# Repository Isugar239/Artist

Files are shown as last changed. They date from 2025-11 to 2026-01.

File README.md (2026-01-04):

# Artist
### here are all files of project "ETZ_Zakharov"
## Schemas
### all schemas were made in Splan8.0
## Programm
### .h files were made in VSCode, without chatGPT
### main file contains all classes from .h files avoid Stepper(you dont need to use it, cause it contains in cart class)
## 3D
### mostly model was made in Autodesk Inventor 24. toothed_rack was downloaded in .step format from mipt site. main file is "робот.ipt"

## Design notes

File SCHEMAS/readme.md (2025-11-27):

# Все схемы выполнены в соответствии с гостом, актуальным на момент создания данного файла

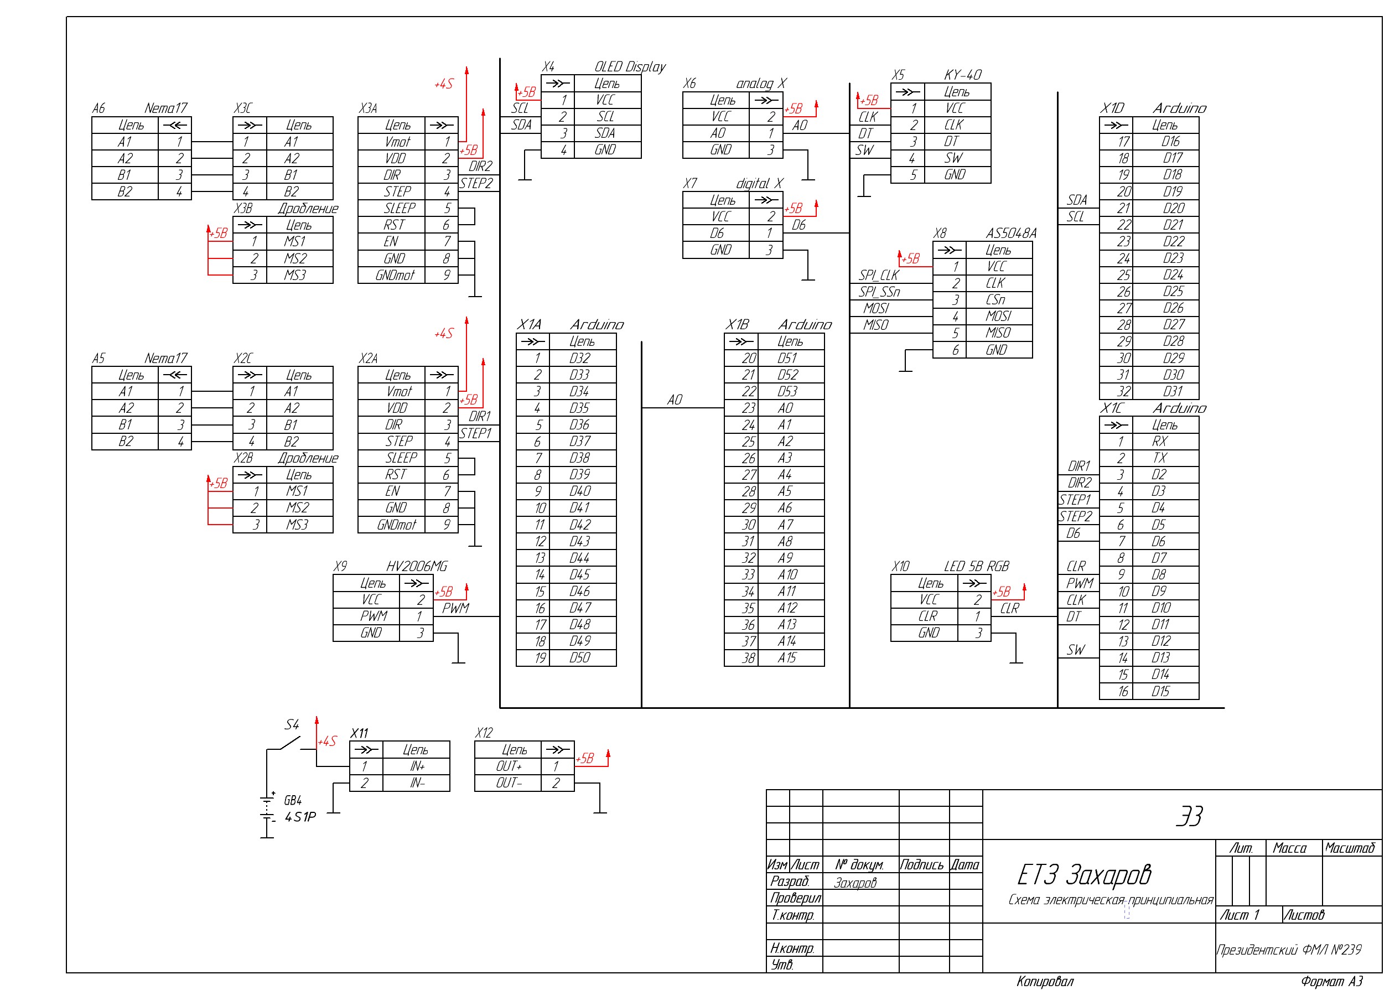
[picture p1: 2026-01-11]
SCHEMAS/Э3_ЕТЗ.jpg

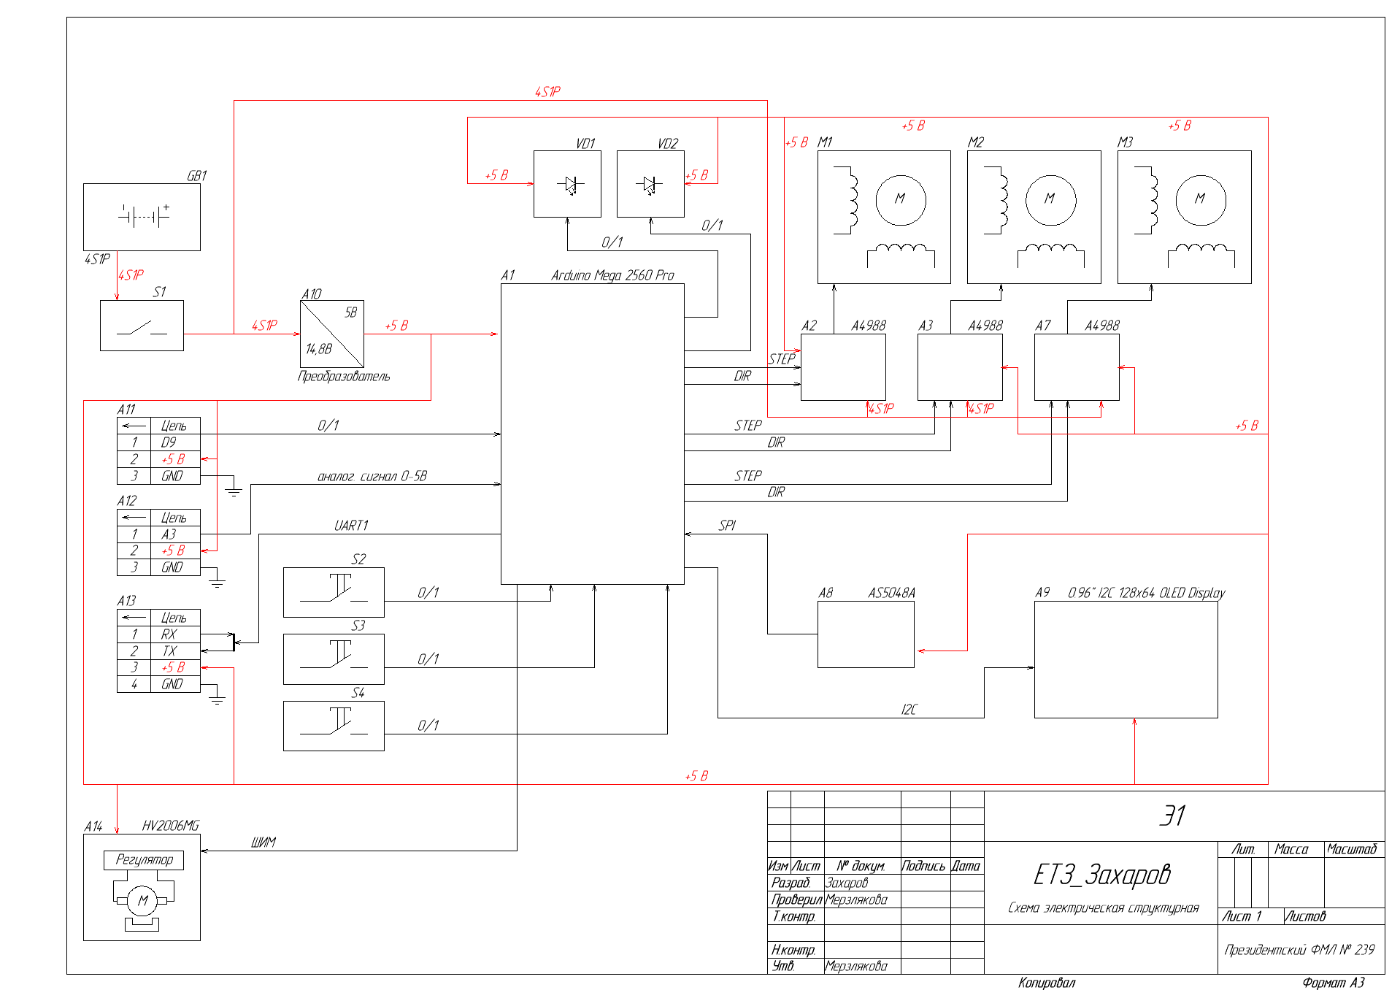
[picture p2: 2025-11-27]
SCHEMAS/Э1_ЕТЗ.png

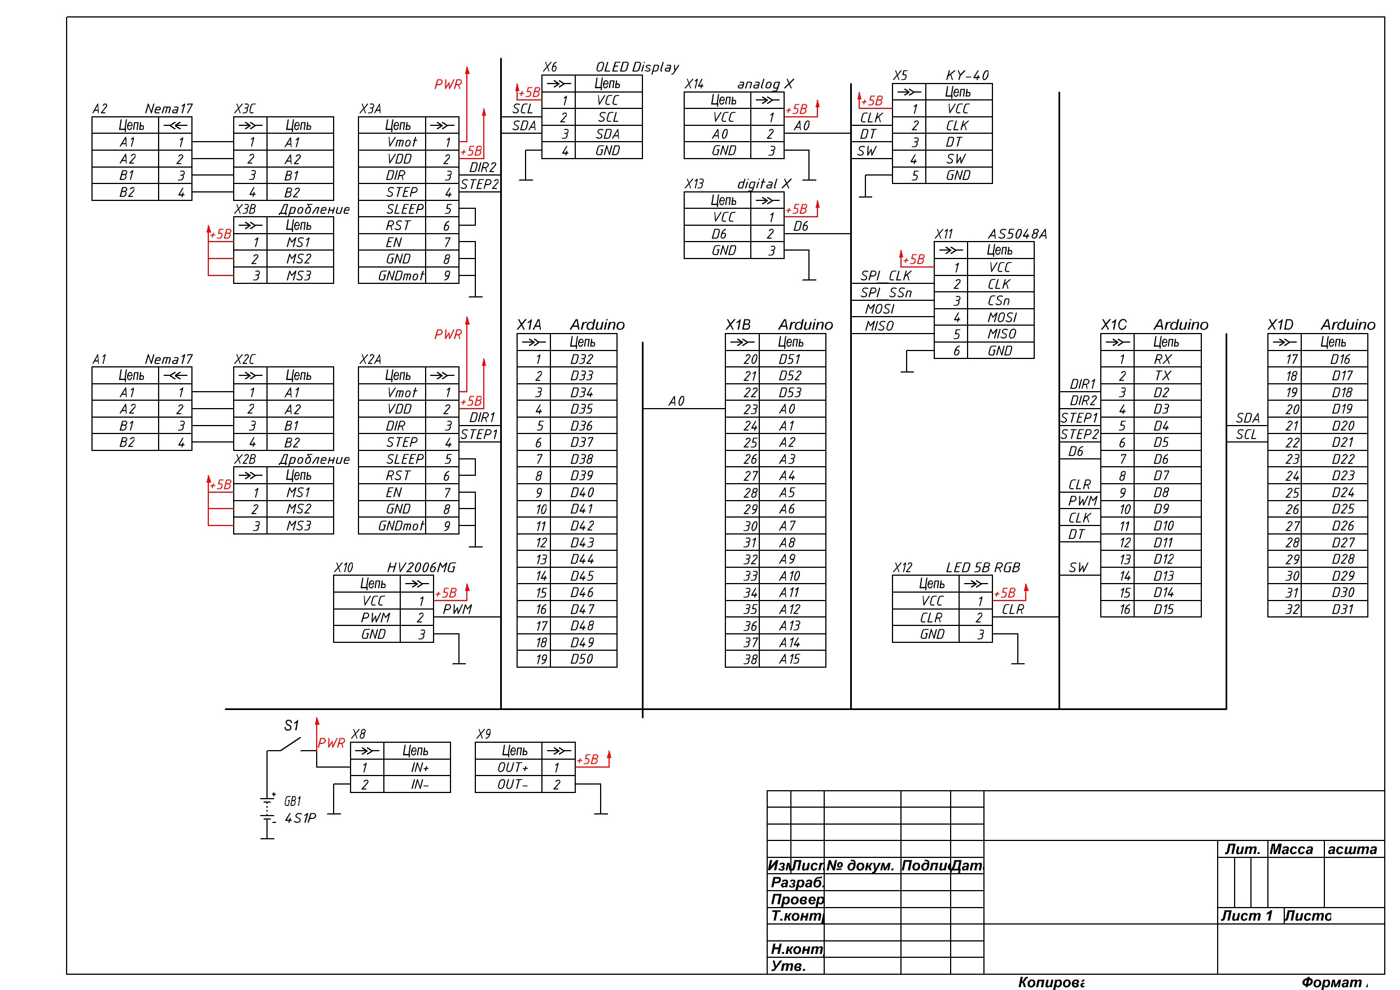
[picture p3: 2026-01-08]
SCHEMAS/э3.jpg

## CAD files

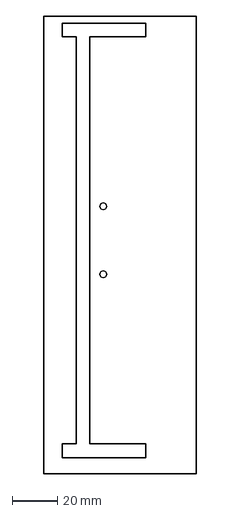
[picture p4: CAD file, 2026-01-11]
3D/dxf/батарейно держалка.dxf
67.3 x 202.1 mm

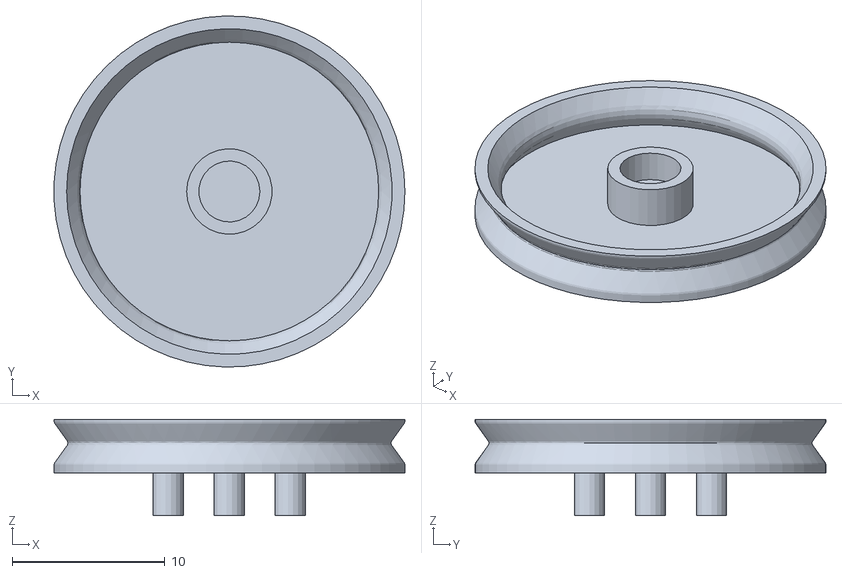
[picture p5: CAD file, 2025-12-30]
3D/для резинки.stl
23.0 x 23.0 x 6.30

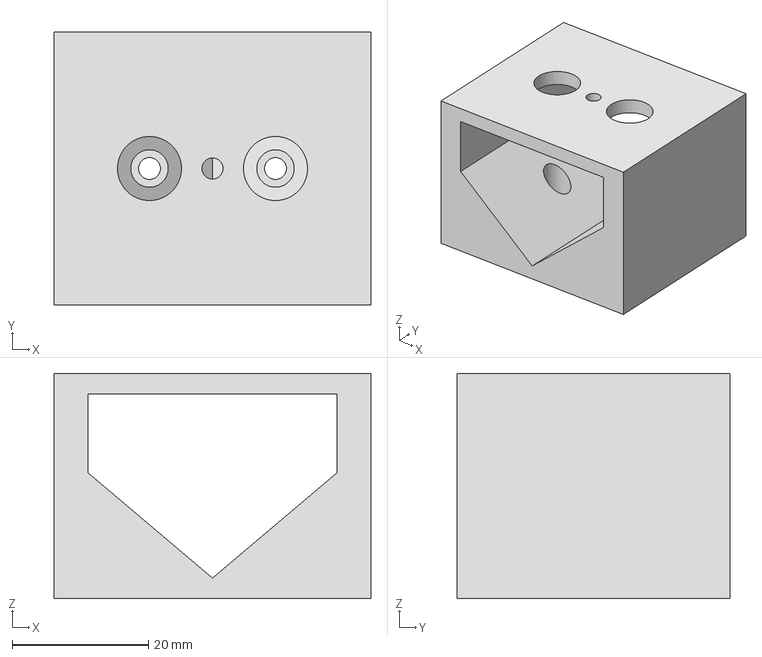
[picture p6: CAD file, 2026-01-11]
3D/стл/верх крепления маркера.stp
46.5 x 40.0 x 33.0 mm

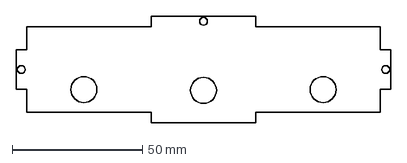
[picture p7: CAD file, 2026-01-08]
3D/dxf/X2_down_balls_mount2.dxf
144.0 x 41.0 mm

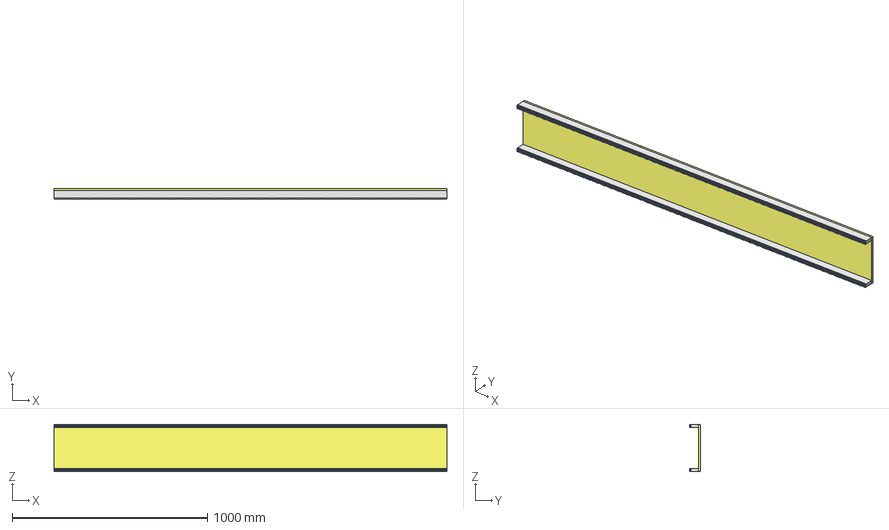
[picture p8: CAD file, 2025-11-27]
3D/полигон етз.stp
2010.6 x 58.0 x 242.7 mm
пол
m2_20_CPY x 10
m2_20_MIR x 10
m2_20_CPY_MIR x 10
брусок
низочек

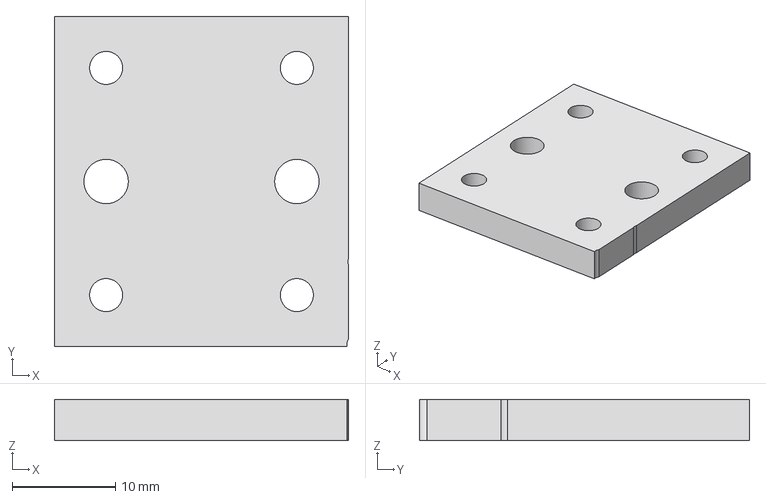
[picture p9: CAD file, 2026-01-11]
3D/стл/полное крепление каретки.stp
28.5 x 32.0 x 4.00 mm

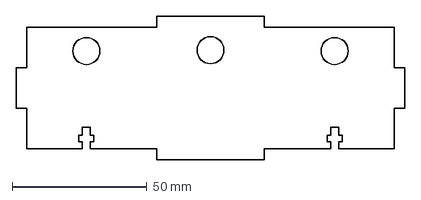
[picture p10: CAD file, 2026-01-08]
3D/dxf/X4_top_mount_balls.dxf
144.0 x 53.0 mm

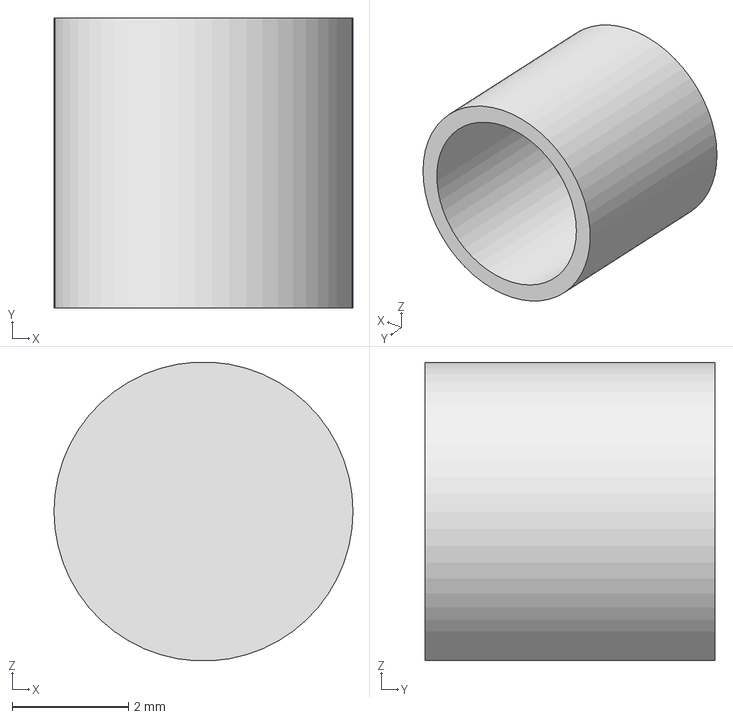
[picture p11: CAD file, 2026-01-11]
3D/стл/на винт для маркера.stp
5.15 x 5.00 x 5.14 mm

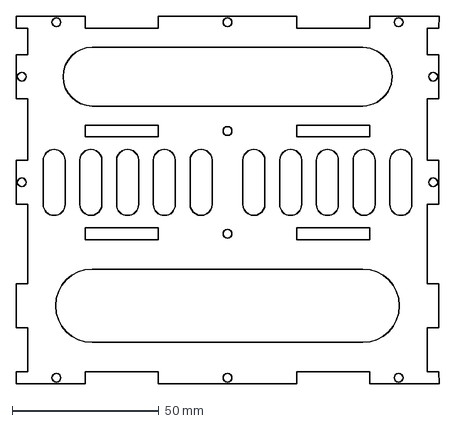
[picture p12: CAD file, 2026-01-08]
3D/dxf/X2_last.dxf
144.0 x 125.0 mm

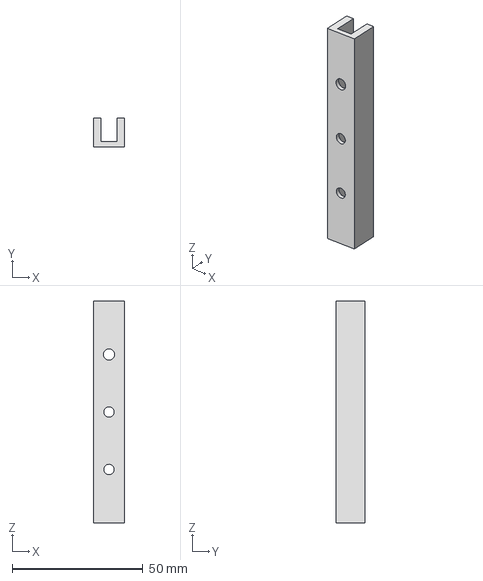
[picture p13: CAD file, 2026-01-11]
3D/стл/красивые провода.stp
12.0 x 11.0 x 85.0 mm

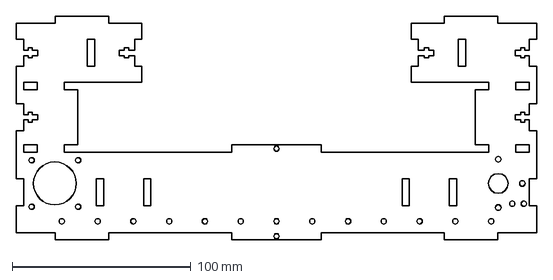
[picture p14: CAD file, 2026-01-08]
3D/dxf/mount_rail.dxf
290.9 x 125.0 mm

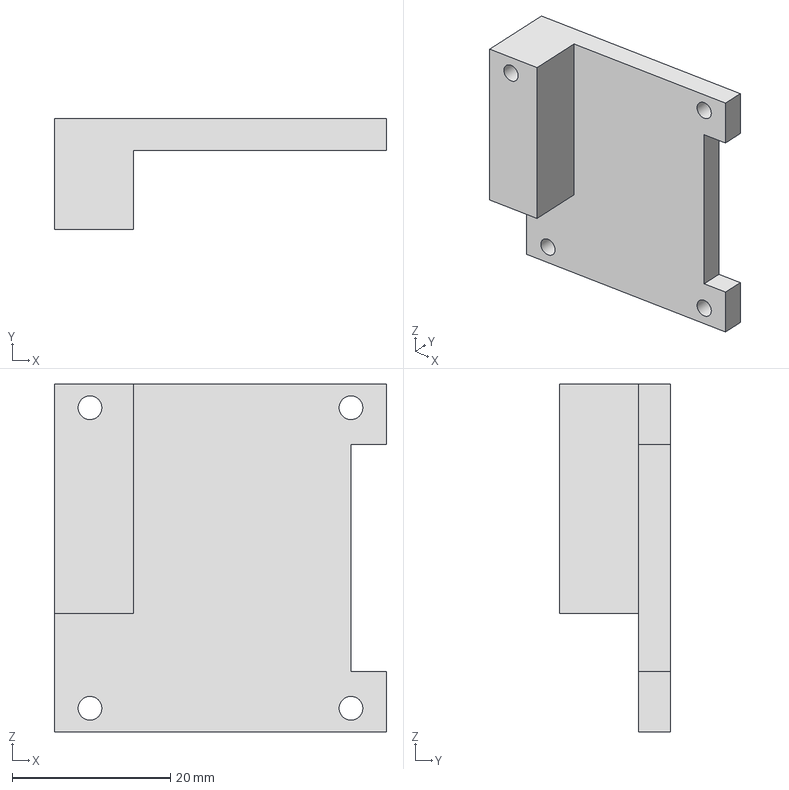
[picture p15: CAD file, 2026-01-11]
3D/стл/экранчик.stp
42.0 x 14.0 x 44.0 mm

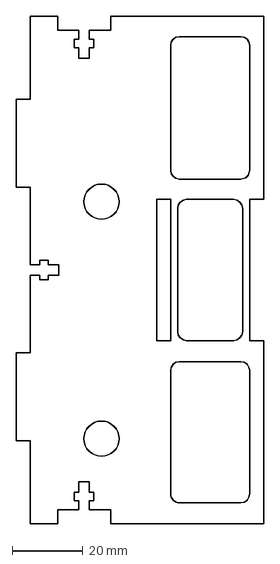
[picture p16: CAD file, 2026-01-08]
3D/dxf/X2_down_down.dxf
70.2 x 144.0 mm

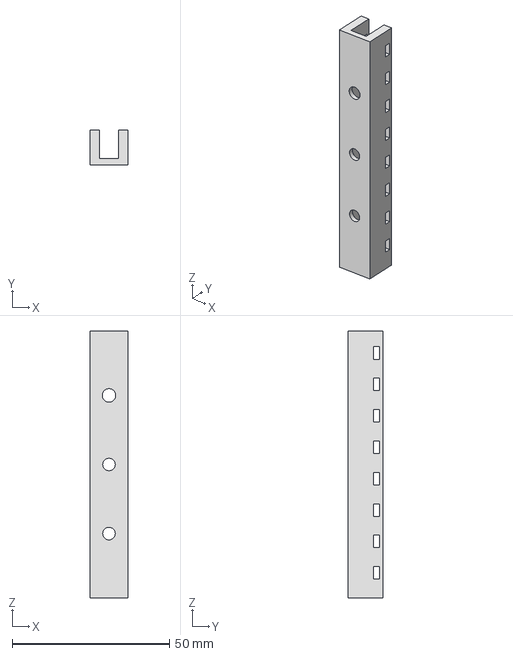
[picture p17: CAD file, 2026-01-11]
3D/стл/новые нормальные провода.stp
12.0 x 11.0 x 85.0 mm

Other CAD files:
3D/полигон_рейки.stl
3D/dxf/задняя крыгка.dxf
3D/стл/крепеж_маркера.stp
3D/dxf/baze_under.dxf
3D/NEMA17 42-40.ipt
3D/OldVersions/NEMA17 42-40.0002.ipt
3D/OldVersions/abs_encider.0002.iam
3D/OldVersions/ЕТЗ.0001.iam
3D/OldVersions/Муфта.0007.ipt
3D/OldVersions/Муфта_MIR.0003.ipt
3D/OldVersions/Нижняя крышка.0019.ipt
3D/OldVersions/ОСНОВА.0005.ipt
3D/OldVersions/Робот.0029.iam
3D/OldVersions/Шест.0007.ipt
3D/OldVersions/Шест_MIR.0002.ipt
3D/OldVersions/боковая стенка.0019.ipt
3D/OldVersions/для резинки.0004.ipt
3D/OldVersions/дно_пробитое.0001.ipt
3D/OldVersions/задняя стенка.0019.ipt
3D/OldVersions/каретка.0008.iam
3D/OldVersions/крепление подшипника_1.0003.ipt
3D/OldVersions/крепление подшипника_1_CPY.0002.ipt
3D/OldVersions/крутящаяся передача.0005.ipt
3D/OldVersions/передняя стенка.0015.ipt
3D/OldVersions/робот-энкодер.0006.ipt
3D/OldVersions/фуллл.0001.iam
3D/abs_encider.iam
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

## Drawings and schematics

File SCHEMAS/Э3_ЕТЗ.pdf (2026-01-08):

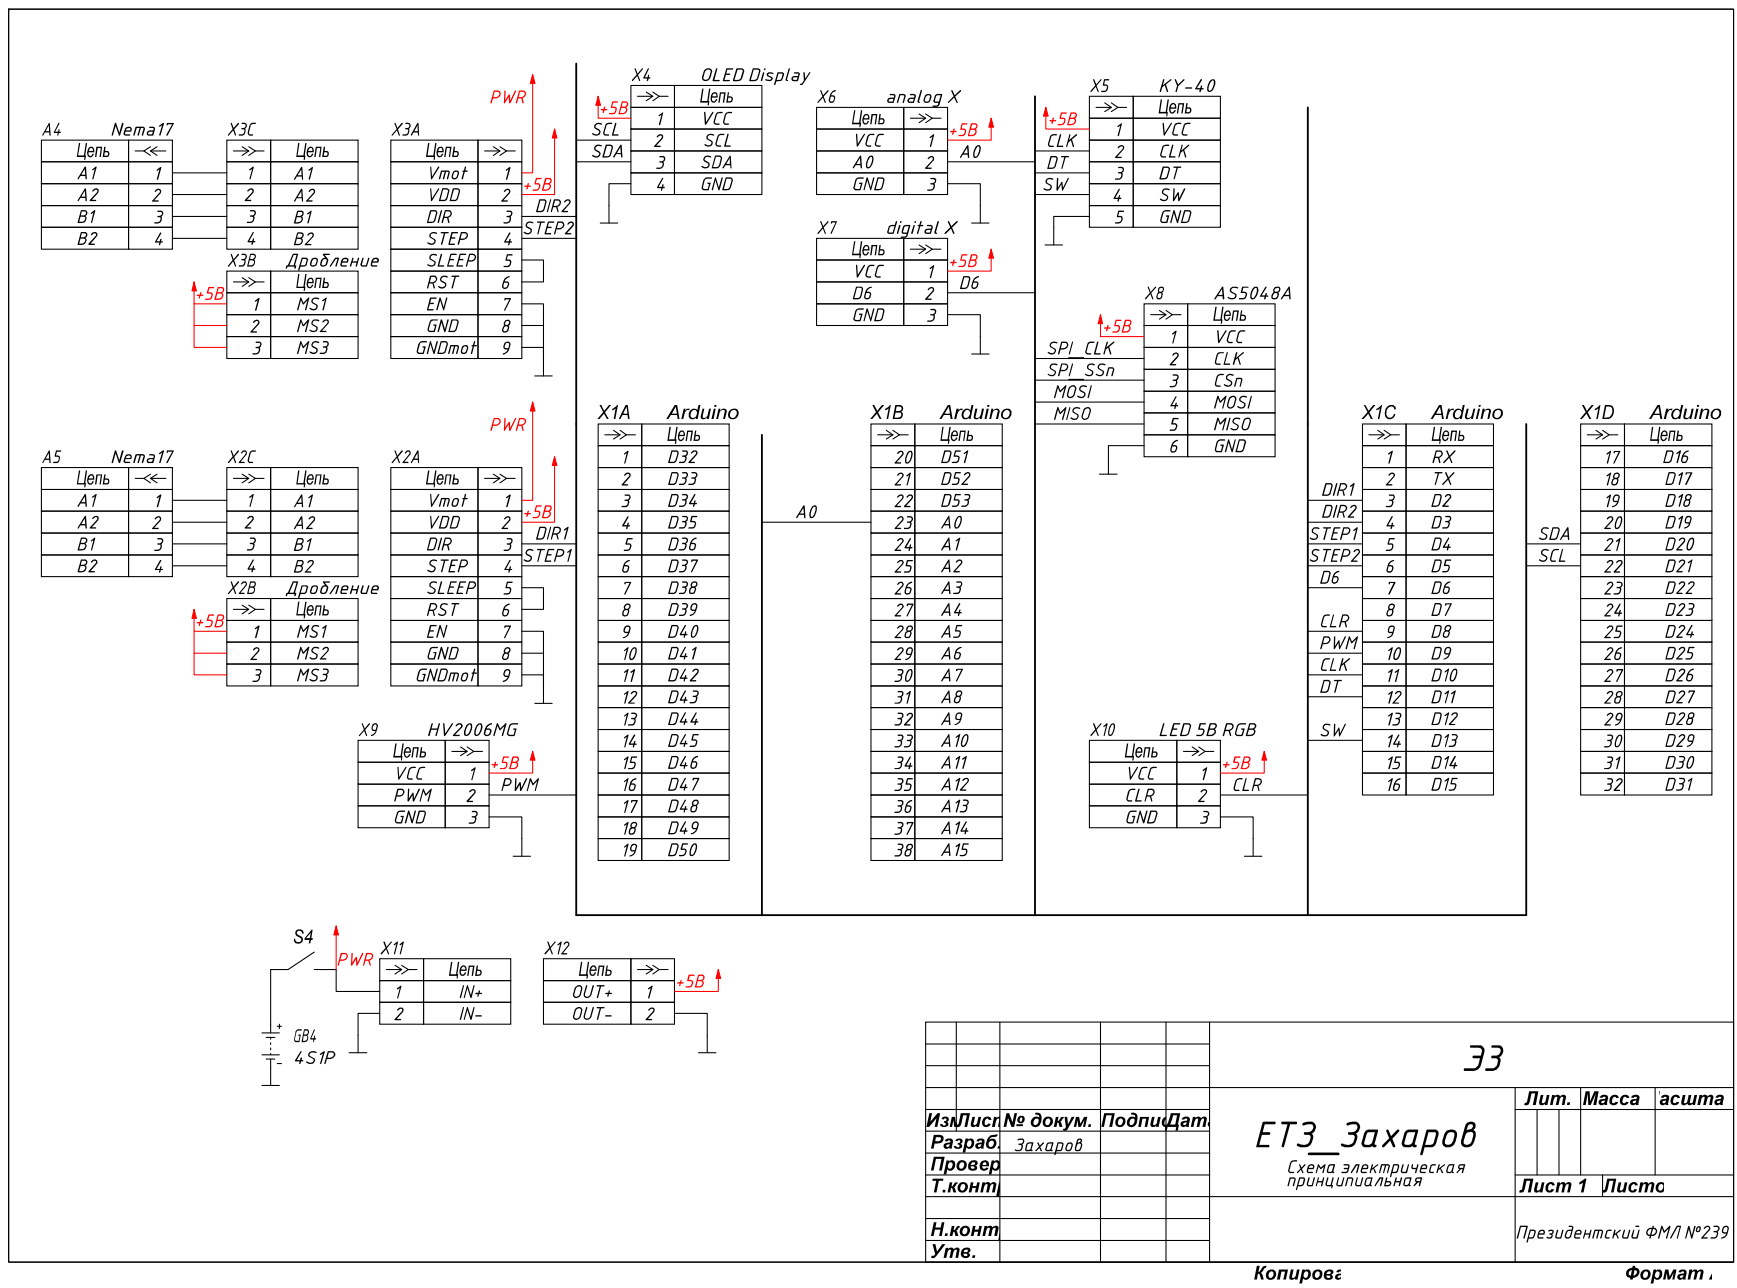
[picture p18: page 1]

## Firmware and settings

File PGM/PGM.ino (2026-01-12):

#include <GyverOLED.h>
#include <Wire.h>
#include "GyverOLEDMenu.h"
#include "cart.h"
#include "encoder.h"
#include "rgb.h"
#include "sensor.h"
#include "marker.h"

int offset = 0;
Sensor sensor;
GyverOLED<SSD1306_128x64> oled;
Encoder enc(10, 11, 12);
cart IvanTM(1, 2, 4, 3, 5);
rgb<8, 3> fara(3, 100);
marker black(9, 90, 270, IvanTM);
Sensor tcrt(A1);
OledMenu<6, GyverOLED<SSD1306_128x64>> menu(&oled);
int gray;
static const unsigned char PROGMEM image_Connect_me_bits[] = {0x00,0x00,0x00,0x00,0x00,0x00,0x00,0x00,0x00,0x00,0x00,0x00,0x00,0x00,0x00,0x00,0x00,0x00,0x00,0x00,0x00,0x00,0x00,0x00,0x00,0x00,0x00,0x00,0x00,0x00,0x00,0x00,0x00,0x00,0x00,0xff,0xff,0xfc,0x00,0x00,0x00,0x00,0x00,0x00,0x00,0x00,0x00,0x00,0x00,0x00,0x00,0xff,0xff,0xfc,0x00,0x00,0x00,0x00,0x00,0x00,0x00,0x00,0x00,0x00,0x00,0x00,0x0f,0x00,0x00,0x03,0xc0,0x00,0x00,0x00,0x00,0x00,0x00,0x00,0x00,0x00,0x00,0x00,0x0f,0x00,0x00,0x03,0xc0,0x00,0x00,0x00,0x00,0x00,0x00,0x00,0x00,0x00,0x00,0x00,0xf0,0x00,0x00,0x00,0x3c,0x00,0x00,0x00,0x00,0x00,0x00,0x00,0x00,0x00,0x00,0x00,0xf0,0x00,0x00,0x00,0x3c,0x00,0x00,0x00,0x00,0x00,0x00,0x00,0x00,0x00,0x00,0x03,0x00,0x00,0x00,0x00,0x03,0x00,0x00,0x00,0x00,0x00,0x00,0x00,0x00,0x00,0x00,0x03,0x00,0x00,0x00,0x00,0x03,0x00,0x00,0x00,0x00,0x00,0x00,0x00,0x00,0x00,0x00,0x0c,0x00,0x00,0x00,0x00,0x00,0xc0,0x00,0x00,0x00,0x00,0x0f,0xfc,0x00,0x00,0x00,0x0c,0x00,0x00,0x00,0x00,0x00,0xc0,0x00,0x00,0x00,0x00,0x0f,0xfc,0x00,0x00,0x00,0x30,0x00,0x00,0x00,0x00,0x00,0x30,0x00,0x00,0x00,0x00,0x0c,0x0c,0x00,0x00,0x00,0x30,0x00,0x00,0x00,0x00,0x00,0x30,0x00,0x00,0x00,0x00,0x0c,0x0c,0x00,0x00,0x00,0xc0,0x00,0x00,0x00,0x00,0x00,0x30,0x00,0x00,0x00,0x00,0x0f,0x3c,0x00,0x00,0x00,0xc0,0x00,0x00,0x00,0x00,0x00,0x30,0x00,0x00,0x00,0x00,0x0f,0x3c,0x00,0x00,0x00,0xc0,0x00,0x00,0x00,0x00,0x00,0x0c,0x00,0x00,0x00,0x00,0x0c,0x0c,0x00,0x00,0x00,0xc0,0x00,0x00,0x00,0x00,0x00,0x0c,0x00,0x00,0x00,0x00,0x0c,0x0c,0x00,0x00,0x03,0x00,0x00,0xff,0x00,0x00,0x00,0x0c,0x03,0xfc,0x00,0x00,0x0f,0xfc,0x00,0x00,0x03,0x00,0x00,0xff,0x00,0x00,0x00,0x0c,0x03,0xfc,0x00,0x00,0x0f,0xfc,0x00,0x00,0x03,0x00,0x03,0x00,0xc0,0x00,0x00,0x03,0x3c,0x03,0x00,0x00,0x30,0x03,0x00,0x00,0x03,0x00,0x03,0x00,0xc0,0x00,0x00,0x03,0x3c,0x03,0x00,0x00,0x30,0x03,0x00,0x00,0x0c,0x00,0x0c,0xff,0x30,0x00,0x00,0x03,0xc0,0x00,0xc0,0x00,0x30,0x03,0x00,0x00,0x0c,0x00,0x0c,0xff,0x30,0x00,0x00,0x03,0xc0,0x00,0xc0,0x00,0x30,0x03,0x00,0x00,0x0c,0x00,0x33,0xf3,0xcc,0x00,0x00,0x3c,0x00,0x00,0xc0,0x00,0x30,0x03,0x00,0x00,0x0c,0x00,0x33,0xf3,0xcc,0x00,0x00,0x3c,0x00,0x00,0xc0,0x00,0x30,0x03,0x00,0x00,0x0c,0x00,0x33,0xf0,0xcc,0x00,0x03,0xc0,0x00,0x3f,0xc0,0x00,0x30,0x03,0x00,0x00,0x0c,0x00,0x33,0xf0,0xcc,0x00,0x03,0xc0,0x00,0x3f,0xc0,0x00,0x30,0x03,0x00,0x00,0x0c,0x00,0x33,0xff,0xcc,0x00,0x3c,0x00,0x03,0xff,0x00,0x00,0x30,0x03,0x00,0x00,0x0c,0x00,0x33,0xff,0xcc,0x00,0x3c,0x00,0x03,0xff,0x00,0x00,0x30,0x03,0x00,0x00,0x30,0x00,0x33,0xff,0xcc,0x00,0x00,0x00,0x0f,0xfc,0x00,0x00,0x30,0x03,0x00,0x00,0x30,0x00,0x33,0xff,0xcc,0x00,0x00,0x00,0x0f,0xfc,0x00,0x00,0x30,0x03,0x00,0x00,0x30,0x00,0x0c,0xff,0xf0,0x00,0x00,0x00,0xff,0xf0,0x00,0x00,0x30,0x03,0x00,0x00,0x30,0x00,0x0c,0xff,0xf0,0x00,0x00,0x00,0xff,0xf0,0x00,0x00,0x30,0x03,0x00,0x00,0x30,0x00,0x03,0x30,0x0c,0x00,0x00,0x03,0xff,0xc0,0x00,0x00,0x3f,0xff,0x00,0x00,0x30,0x00,0x03,0x30,0x0c,0x00,0x00,0x03,0xff,0xc0,0x00,0x00,0x3f,0xff,0x00,0x00,0x30,0x00,0x00,0xc0,0x00,0x00,0x00,0x0f,0xff,0x00,0x00,0x00,0x03,0x30,0x00,0x00,0x30,0x00,0x00,0xc0,0x00,0x00,0x00,0x0f,0xff,0x00,0x00,0x00,0x03,0x30,0x00,0x00,0x30,0x00,0x00,0xc0,0x00,0x00,0x00,0x3f,0xfc,0x00,0x00,0x00,0x03,0x30,0x00,0x00,0x30,0x00,0x00,0xc0,0x00,0x00,0x00,0x3f,0xfc,0x00,0x00,0x00,0x03,0x30,0x00,0x00,0x30,0x00,0x00,0x00,0x00,0x00,0x00,0xff,0xf0,0x00,0x00,0x00,0x03,0x30,0x00,0x00,0x30,0x00,0x00,0x00,0x00,0x00,0x00,0xff,0xf0,0x00,0x00,0x00,0x03,0x30,0x00,0x00,0x30,0x00,0x00,0x00,0x30,0x00,0x0f,0x00,0xff,0xff,0x00,0x00,0x03,0xf0,0x00,0x00,0x30,0x00,0x00,0x00,0x30,0x00,0x0f,0x00,0xff,0xff,0x00,0x00,0x03,0xf0,0x00,0x00,0x30,0x00,0x00,0x00,0x0f,0x00,0xf0,0x00,0x0f,0xf0,0xc0,0x00,0x00,0xc0,0x00,0x00,0x30,0x00,0x00,0x00,0x0f,0x00,0xf0,0x00,0x0f,0xf0,0xc0,0x00,0x00,0xc0,0x00,0x00,0x30,0x00,0x00,0x00,0x00,0xff,0xff,0xff,0xf0,0x00,0xc0,0x00,0x03,0xff,0x00,0x00,0x30,0x00,0x00,0x00,0x00,0xff,0xff,0xff,0xf0,0x00,0xc0,0x00,0x03,0xff,0x00,0x00,0x30,0x00,0x00,0x00,0x00,0x00,0x00,0x00,0x00,0x00,0xc0,0x00,0x0c,0x00,0xf0,0x00,0x30,0x00,0x00,0x00,0x00,0x00,0x00,0x00,0x00,0x00,0xc0,0x00,0x0c,0x00,0xf0,0x00,0x30,0x00,0x00,0x00,0x00,0x00,0x00,0x00,0x00,0x03,0x00,0x00,0x30,0x00,0x0c,0x00,0x30,0x00,0x00,0x00,0x00,0x00,0x00,0x00,0x00,0x03,0x00,0x00,0x30,0x00,0x0c,0x00,0x30,0x00,0x00,0x00,0x00,0x00,0x00,0x00,0x00,0xfc,0x00,0x00,0x30,0x00,0x03,0x00,0x30,0x00,0x00,0x00,0x00,0x00,0x00,0x00,0x00,0xfc,0x00,0x00,0x30,0x00,0x03,0x00,0x30,0x00,0x00,0x00,0x00,0x00,0x00,0x00,0x0f,0x00,0x00,0x00,0x30,0x00,0x00,0xc0,0x30,0x00,0x00,0x00,0x00,0x00,0x00,0x00,0x0f,0x00,0x00,0x00,0x30,0x00,0x00,0xc0,0x30,0x00,0x00,0x00,0x00,0x00,0x3f,0xff,0xf0,0x00,0x00,0x00,0x0f,0x00,0x00,0xc0,0x30,0x00,0x00,0x00,0x00,0x00,0x3f,0xff,0xf0,0x00,0x00,0x00,0x0f,0x00,0x00,0xc0,0x30,0x00,0x00,0x00,0x00,0x00,0x03,0xff,0xc0,0x00,0x00,0x00,0x00,0xc0,0x00,0x30,0x30,0x00,0x00,0x00,0x00,0x00,0x03,0xff,0xc0,0x00,0x00,0x00,0x00,0xc0,0x00,0x30,0x30,0x00,0x00,0x00,0x00,0x00,0x00,0x00,0xc0,0x00,0x00,0x00,0x00,0xf0,0x00,0x30,0x30,0x00,0x00,0x00,0x00,0x00,0x00,0x00,0xc0,0x00,0x00,0x00,0x00,0xf0,0x00,0x30};



void blackline(){
   IvanTM.setPos(0);
  while (true) {
    int sen = analogRead(A1);
    // Serial.println(analogRead(A1));

    if (sen < gray) {
      IvanTM.tick();
      // Serial.println(IvanTM.getPos());

    } else {
      Serial.println(analogRead(A1));

      break;
    }
    //  Serial.print("pos=");
    // Serial.println(IvanTM.getPos());
  }
  Serial.println("Start to doinf smth");
  Serial.print("Pos = ");
  Serial.println(IvanTM.getPos());
  IvanTM.gotoPos(IvanTM.getPos() - 49);
  IvanTM.setZero();
  IvanTM.gotoPos(-60);
}
void func1() {
  oled.clear();

  oled.update();
  fara.green();
 for(int i = 0;  i< 10; i++){
  fara.white();
  IvanTM.gotoPos(i*10);
  fara.yellow();
  black.down();
  delay(500);
  black.up();

 }
IvanTM.gotoPos(-60);
  oled.setScale(1);
  fara.clear();
  menu.showMenu(true);
  oled.update();
}

void func2() {
  IvanTM.gotoPos(0);
  black.down();
  black.up();
IvanTM.gotoPos(100);
black.down();
black.up();
}

void func3() {
  black.down();
}

void func4() {
  black.up();
}

void func5() {
  black.up();
  int bl= analogRead(A1), wl=analogRead(A1);
  IvanTM.setPos(100);
  while (IvanTM.tick()) {
    int sen = analogRead(A1);
    if (sen > bl)
      bl = sen;

    if (sen < wl)
      wl = sen;
  }
  gray = (bl + wl) / 6;

  Serial.print("GRAY=");
  Serial.println(gray);
 blackline();
}

void func6() {
  for(int i = 0; i<10; i+=2){
  black.drawLine(i*10, (i+1)*10);
}}
void func7(){}
void (*menuFuncs[7])() = { func1, func2, func3, func4, func5, func6, func7 };

const char* menuNames[6] = {
  "1", "2", "donw",
  "up", "calibr", "6"
};

// Колбэк при выборе пункта меню
void onItemChange(const int index, const void* val, const byte valType) {  //чтобы просто прокрутка не вызывала функцию, а именно тык по ней
  if (valType == VAL_ACTION) {
    if (index >= 0 && index < 7) {
      Serial.println(index);
      menuFuncs[index]();  // указатель вызывает функцию
    }
  }
}

void encoderCallback() {
  if (enc.dir != 0) {
    if (enc.dir == 1) {
      menu.selectNext(false);  //false значит без скипов элементов
    } else {
      menu.selectPrev(false);
    }
    oled.update();
  }

  if (enc.clicked) {
    menu.toggleChangeSelected();
    oled.update();
  }
}

void setup() {
  oled.init();
  Wire.setClock(400000L);
  oled.clear();
  oled.update();
  Serial.begin(9600);
  black.begin();
  
oled.drawBitmap(0, 0, image_Connect_me_bits, 124, 62, 1);

oled.update();
delay(1200);
  menu.onChange(onItemChange, false);

  menu.addItem(PSTR("1"));
  menu.addItem(PSTR("2"));
  menu.addItem(PSTR("DOwn"));
  menu.addItem(PSTR("Up"));
  menu.addItem(PSTR("calibrovka"));
  menu.addItem(PSTR("6"));
  menu.addItem(PSTR("7"));

  menu.showMenu(true);
  fara.begin();
  Serial.println("inited");

  while (enc.clicked) { enc.tick(); }
}

void loop() {
  enc.tick();
  encoderCallback();
  sensor.tick();
  IvanTM.tick();
}

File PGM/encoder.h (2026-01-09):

#pragma once
#include <Arduino.h>

class Encoder {
private:
  int pinA;
  int pinB;
  int pinTouchButton;
  bool prevA;
  bool prevTouchBtn;

public:
  int dir;
  bool clicked;

  Encoder(int a, int b, int touchButton)
    : pinA(a), pinB(b), pinTouchButton(touchButton), prevA(false), prevTouchBtn(false), dir(0), clicked(false)
  {
    pinMode(pinA, INPUT_PULLUP);
    pinMode(pinB, INPUT_PULLUP);
    pinMode(pinTouchButton, INPUT_PULLUP);
    prevA = digitalRead(pinA);
    prevTouchBtn = digitalRead(pinTouchButton);
  }

  void tick() {
  bool currA = digitalRead(pinA);
  bool currB = digitalRead(pinB);

  dir = 0;

  if (!prevA && currA) {
    dir = currB ? -1 : 1;
  }

  prevA = currA;
  if(digitalRead(pinTouchButton) != prevTouchBtn){
    clicked=digitalRead(pinTouchButton);
    prevTouchBtn = clicked;
  }
}

};

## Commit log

2025-11-22 added 3d model folder
    [NEMA17 42-40.ipt, ЕТЗ.0001.iam, Муфта.0002.ipt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]
2025-11-24 я сделал выравнивание по ох
    работает
    [Нижняя крышка.0003.ipt, Нижняя крышка.ipt, Робот.0002.iam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]
2025-11-25 крепление подшипника
    [боковая стенка.0009.ipt, боковая стенка.0011.ipt, боковая стенка.ipt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]
2025-11-25 аплоуд Э1
2025-11-27 добавлен полигон етз с завивимостью
    [NEMA17 42-40.0002.ipt, NEMA17 42-40.ipt, abs_encider.0002.iam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]
2025-12-01 ВЫРУБИЛИ СВЕТ И Я ОСТАЛСЯ БЕЗ ЗАМОДЕЛЕННОЙ КАРЕТКИ
    [A137 Высокоточная прокладка O 5,3 O 8.ipt, A172 Стандартный пластиковый ролик для V-паза.ipt, A181 Подшипник 625rs, O 5 O 16.ipt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]
2025-12-01 я востановился
    [Нижняя крышка.0009.ipt, Нижняя крышка.0011.ipt, Нижняя крышка.ipt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]
2025-12-02 делаю крепление для маркера(скоро прак муниципа, спасите)
    [Робот.0012.iam, Робот.0013.iam, Робот.iam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]
2025-12-03 вася дал правки
    [Цилиндрическое зубчатое зацепление1.iam, Цилиндрическое зубчатое зацепление11.ipt, боковая стенка.0012.ipt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]
2025-12-06 сделал крышку взамен потеряной
    [k400+ крышка.ipt, k400+ крышка.stl, Нижняя крышка.0011.ipt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]
2025-12-08 вырезал(оно собирается) и пофиксил заднее правое верхнее крепление
    [k400+ крышка.0002.ipt, k400+ крышка.ipt, k400+ полная.0001.iam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]
2025-12-10 теперь макетка ставится на ура
    [низ_обновленный.dxf]
2025-12-20 я боюсь теории
    [Муфта.0004.ipt, Муфта.0005.ipt, Муфта.ipt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]
2025-12-29 понаписал классов тележки с 2 моторами и маркера
2025-12-30 норм держалка для вала ведомого
    [Муфта.stl, Муфта.stp, Шест.stl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]
2026-01-02 better kreplenie markerov
    [Муфта.0005.ipt, Муфта.0006.ipt, Муфта.ipt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]
2026-01-04 added own encoder and comments to main file
    [Робот.0019.iam, Робот.0020.iam, Робот.iam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]
2026-01-04 указал про 3д модель
2026-01-04 add sensor
2026-01-07 working screen, going to do drawing block
    [Деталь1.stl, Нижняя крышка.0018.ipt, Нижняя крышка.0019.ipt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]
2026-01-08 NEED TO MAKE MARKER
    [X2_down_balls.dxf, X2_down_balls_mount1.dxf, X2_down_balls_mount2.dxf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]
2026-01-08 норм крепление для маркера
    [крепеж_маркера.ipt, крепеж_маркера.stl]
2026-01-08 пофиксил каретку
    [каретка.0003.iam, каретка.0004.iam, каретка.iam]
2026-01-09 fix marker
    [Робот.0024.iam, Робот.0025.iam, Робот.iam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]
2026-01-11 need to fix allign of marker
    [4s.0001.ipt, 4s.ipt, 4s.stp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]
2026-01-11 пофиксил крепеж чтобы линия была по центру
    [4s.0001.ipt, 4s.0002.ipt, 4s.ipt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]
2026-01-12 fixed allign of marker
    [PGM.ino, cart.h]
2026-01-12 добавил прикольную картинку
